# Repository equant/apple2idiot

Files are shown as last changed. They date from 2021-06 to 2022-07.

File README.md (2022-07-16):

# apple2idiot card
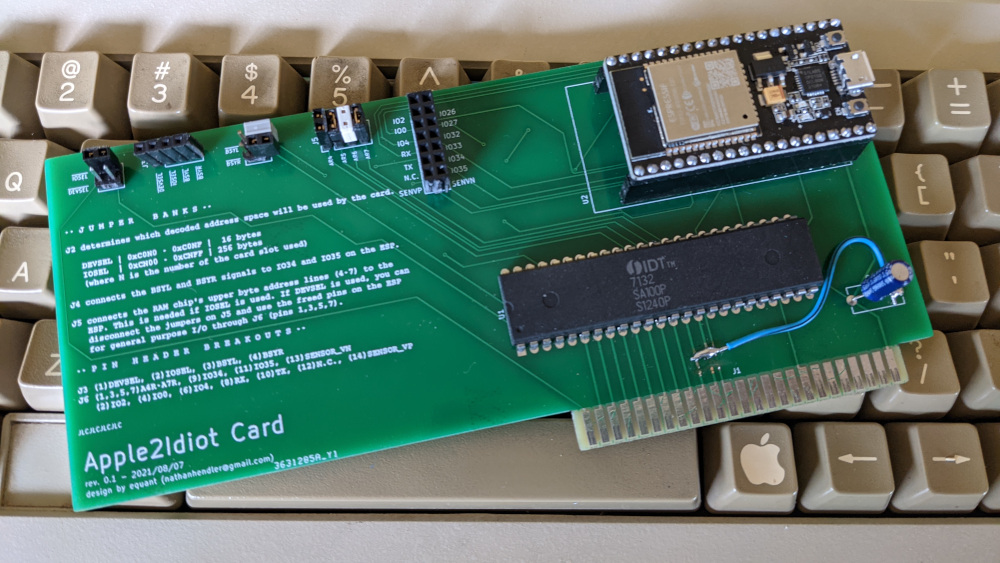
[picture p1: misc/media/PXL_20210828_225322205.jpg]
<br>
A general purpose ESP32 Wifi and Bluetooth board for the Apple II family of
computers (with expansion slots).  

This card is essentially an ESP32 module and a dual-port ram chip.  The Apple
computer and the ESP communicate via the dual-port ram.  That means that the
ESP32 doesn't acutally have access to read/write any of the Apple computer's
data or address busses.  I think that's ok.  In fact, I think this card is so
simple, and stupid, that lots of fun little things can be done with it, but
it's not meant to "get your Apple on the internet".

As a user of the card, you write the software that runs on the ESP32 module,
and the software that runs on the Apple computer.  In the `examples/` folder
are examples of how to do simple little things.  Software on the apple just
peeks/pokes commands and data to the ram chip, and the ESP responds however
it's programmed to resppond.

## Some of the example programs that have been developed so far

* Send a message to Slack.
* Get current weather conditions for a city.
* Select Wifi AP.
* Dedicated rot13 string encoder.

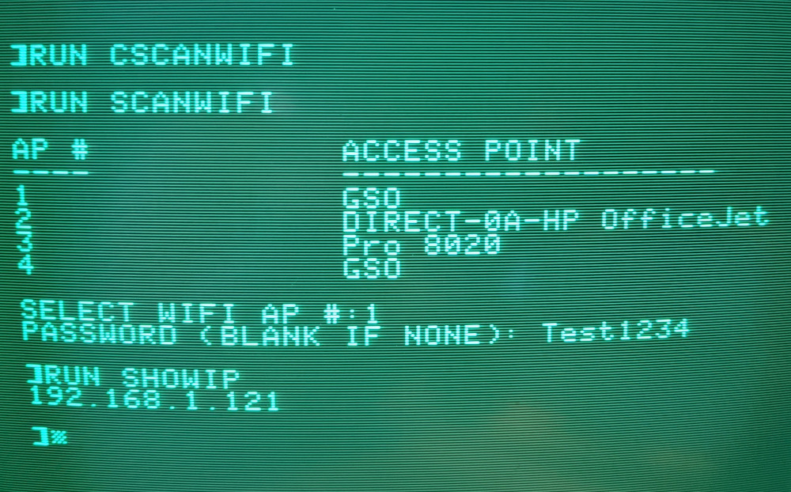
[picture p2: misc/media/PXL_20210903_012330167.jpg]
<br>

## Status

### The Card

This is actively being developed (as of July 2022).  The rev 0.2 boards have arrived, and they work as designed.  The gerber files are here in the repo.

### The Apple II Software

There are examples written in BASIC and in cc65 in the `examples/` directory.

### The Card Software/Firmware

The ESP32 can be programmed using whatever you want.  For example, you can use
the Arduino IDE/C++ or you can use Lua, or Espressif's environment.  Example
Arduino programs are in the repo under examples.

## What could be done with an Apple2Idiot card?

Here are some things I'm interested in making work...

* Prodos clock driver (NTP -> ESP -> Prodos)
* Home automation using MQTT
* Peer-to-peer local area chat/games using ESPNOW or something similar
* Wikipedia access

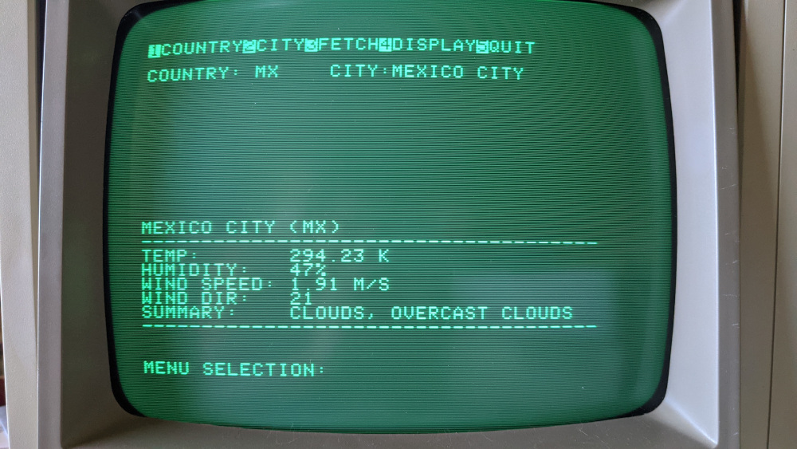
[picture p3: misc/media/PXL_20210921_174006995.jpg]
<br>

## Want to help?

There are lots of jobs both little and big and hard and easy for someone
looking for a project to join.  Take a look at the list above for ideas.  Feel
free to email me at nathanhendler@gmail.com.

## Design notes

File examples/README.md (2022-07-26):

# apple2idiot

## Potential requirements

Some of these examples require things.  Here are some notes I've been taking...

### Arduino Libraries

+ https://github.com/me-no-dev/ESPAsyncWebServer
+ https://github.com/me-no-dev/AsyncTCP
+ ArduinoJSON by Benoit Blanchon

Instructions for installing Arduino libraries: https://www.arduino.cc/en/Guide/Libraries

Download the zips from github...

```bash
cd ~/Arduino/libraries
unzip AsyncTCP-master.zip
unzip ESPAsyncWebServer-master.zip
mv AsyncTCP-master AsyncTCP
mv ESPAsyncWebServer-master ESPAsyncWebServer
```

For ESP32 webserver to serve static files...

+ https://github.com/me-no-dev/arduino-esp32fs-plugin

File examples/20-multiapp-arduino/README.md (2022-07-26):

# Arduno sketch for Apple2 Internet Weather Client Examples

For now, this works with both the basic and and cc65 clients

`../15_fixed_essid_weather-basic`
`../15_fixed_essid_weather-cc65`

if arduino-cli compile --fqbn esp32:esp32:nodemcu-32s .; then arduino-cli upload -p /dev/ttyUSB0 --fqbn esp32:esp32:esp32-poe-iso .; fi

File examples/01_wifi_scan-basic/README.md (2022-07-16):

# Overview

This is a very simple example of how to scan for wifi access points and then
connect to one.  It is a very basic example of how the Apple2Idiot card and the
Apple II can work together.  Practically, this example isn't very useful,
because after you connect you can not really do anything except recscan.
There's no code in `01_wifi_scan-basic.ino` to do anything else.  

## Getting it to work

#. Load `01_wifi_scan-basic.dsk` into your Apple II
#. Load `01_wifi_scan-basic.ino` into your apple2idiot card in slot 2.

At BASIC prompt on Apple II do...

```BASIC
RUN CWIFISCAN.BAS
RUN WIFISCAN.BAS
RUN SHOWIP.BAS
```

CWIFISCAN tells the card to scan for access points.

WIFISCAN shows the results, and lets you choose an access point and enter a password

SHOWIP does just that.

## Building the .dsk image

```bash
. ./make-disk.bash
```

## Flashing card using arduino-cli

You can use the arduino ide to get the .ino file onto the Apple2Idiot card.  Or you can use the `arduino-cli` which is explained here...

```bash
arduino-cli compile --fqbn esp32:esp32:nodemcu-32s .
arduino-cli upload -p /dev/ttyUSB0 --fqbn esp32:esp32:esp32-poe-iso .
```

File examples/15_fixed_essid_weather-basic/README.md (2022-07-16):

# Very simple Apple II Internet weather client example

* Use the arduino-cli or ide to transfer `../15_fixed_essid_weather-arduino/15_fixed_essid_weather-arduino.ino` to the ESP32 on the apple2idiot card.
* Use `WEATHER.BAS` on your Apple ][.

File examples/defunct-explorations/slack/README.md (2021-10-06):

# ESP32 Slack code for apple2idiot

```
~/.arduino15/packages/esp32/hardware/esp32/1.0.6/tools/sdk/sdkconfig
```

Set `CONFIG_SPIRAM_USE_MALLOC=y` to use SPI Ram for heap memory.

## Notes

Sun Sep 26 2021
```
Sketch uses 885078 bytes (67%) of program storage space. Maximum is 1310720 bytes.
Global variables use 40784 bytes (12%) of dynamic memory, leaving 286896 bytes for local variables. Maximum is 327680 bytes.

Sketch uses 884910 bytes (67%) of program storage space. Maximum is 1310720 bytes.
Global variables use 40784 bytes (12%) of dynamic memory, leaving 286896 bytes for local variables. Maximum is 327680 bytes.

Sketch uses 885222 bytes (67%) of program storage space. Maximum is 1310720 bytes.
Global variables use 40784 bytes (12%) of dynamic memory, leaving 286896 bytes for local variables. Maximum is 327680 bytes.

Sketch uses 883538 bytes (67%) of program storage space. Maximum is 1310720 bytes.
Global variables use 40784 bytes (12%) of dynamic memory, leaving 286896 bytes for local variables. Maximum is 327680 bytes.

```

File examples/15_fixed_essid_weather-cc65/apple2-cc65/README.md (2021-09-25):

# Apple2 Internet Weather Client Example

This is the C code to compile the software that runs on an Apple2 and makes use
of the Apple2idiot card to display the weather for a given city.

## How I use this

This is how I compile, make a disk and then stage the disk for transfer to my //c using ADTPro.

```
make
make TARGETS=apple2 dsk
cp weather.dsk ~/bin/ADTPro-2.1.0/disks/
```

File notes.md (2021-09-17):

## Debugging board 08/28/2021

What the ESP thinks is address 0x00 (0xC200) is 0xC2FF,49919 to the Apple.
AND the data from the ESP is 192 and the apple sees 3, so the endian is backwards
for the data and logic levels for the address are flipped.

## Needed changes to board

DONE: Add a GND and +5V breakout.
Fix DEVSEL address in silkscreen docs.
DONE: Unconnect addresses above A7.
DONE: Add diode to +5V.
DONE: Move ESP32 towards keyboard to accomodate USB
Software reset of ESP32

## Potential Trivial Features

+ Gives each computer a unique ID (MAC address)
+ Prodos driver for NPT time.

## Thanks

Renee
flux
c2t

## Ordered:

* 5PCS IDT7132SA100P IDT7132SA DIP-48 HIGH-SPEED 2K x 8 DUAL-PORT STATIC RAM 
* STM32F411 "BlackPill" Development Board

## Misc

* https://pastebin.com/raw/1kR0vbRA

## ESP32 Interupt Issues

* ESP32 Thread I started: https://esp32.com/viewtopic.php?f=12&t=21855
	* " Consider 74ls373 to latch the value to be processed by software."
	* It might also be worth trying ESP32's assembly high-level interrupts. I've never used them personally, but they can allegedly give interrupt latencies that are significantly lower than the ~2us for regular ESP32 C interrupts.
		* See: https://esp32.com/viewtopic.php?t=422
		* See: https://docs.espressif.com/projects/esp ... rupts.html
	* components/esp_system/port/soc/esp32/dport_panic_highint_hdl.S

## Python binar/hex/dec manipulation

```
In [11]: format(10, '016b')
Out[11]: '0000000000001010'

bin(10)
```

## Jumper and Breakout pins

* Input (to ESP32) only
    ~IOSEL  (from Apple2)
    ~BSYL   (from Apple2 side of IDT7132)
    ~BSYR   (from ESP32 side of IDT7132)

+ Apple II Pins to header
    + IOSEL
    + DEVSEL
    + IOSTROBE
+ IDT7132S Pins to header
    + BSYL
    + BSYR
+ ESP32 Pins to header
    + GPIO 0
    + GPIO 1    (TX)
    + GPIO 2
    + GPIO 3    (RX)
    + GPIO 4
    + GPIO 26
    + GPIO 27
    + GPIO 32
    + GPIO 33
    + GPIO 34   (input only) No pullup, needs resistor?
    + GPIO 35   (input only) No pullup, needs resistor?
    + SENSOR_VP (input only) No pullup, needs resistor?
    + SENSOR_VN (input only) No pullup, needs resistor?

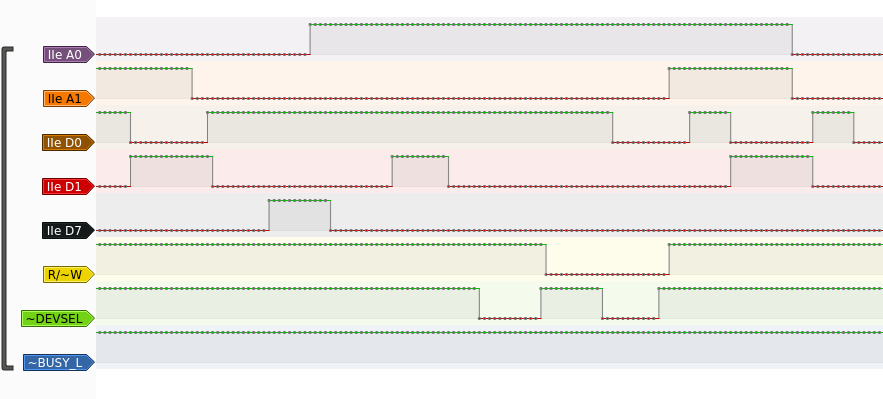
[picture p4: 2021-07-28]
misc/media/pulseview_poke_double_devsel-cropped.png

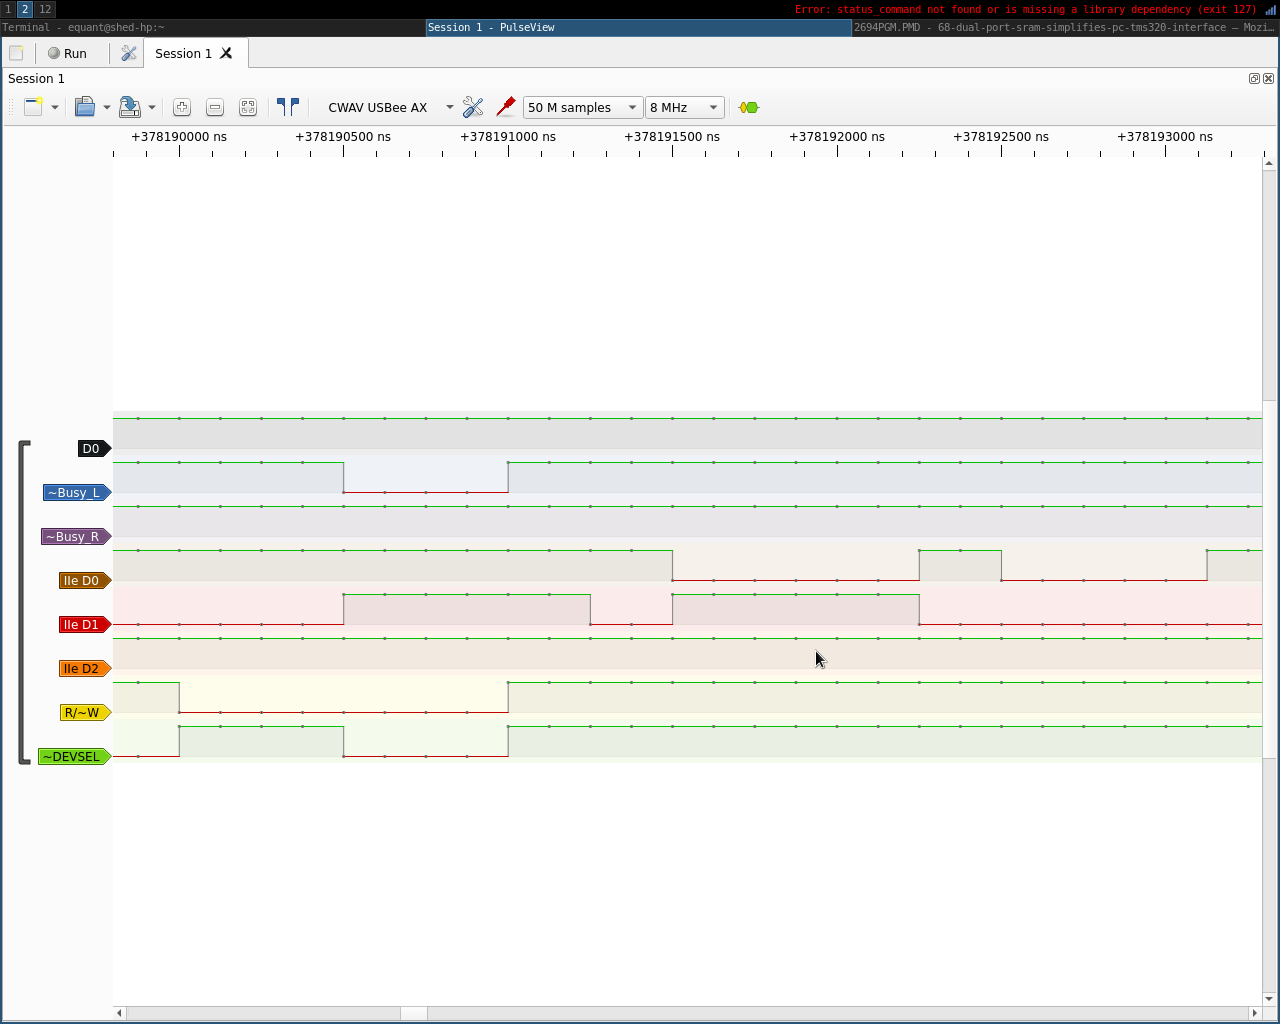
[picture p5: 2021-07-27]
misc/media/pulseview_busy.png

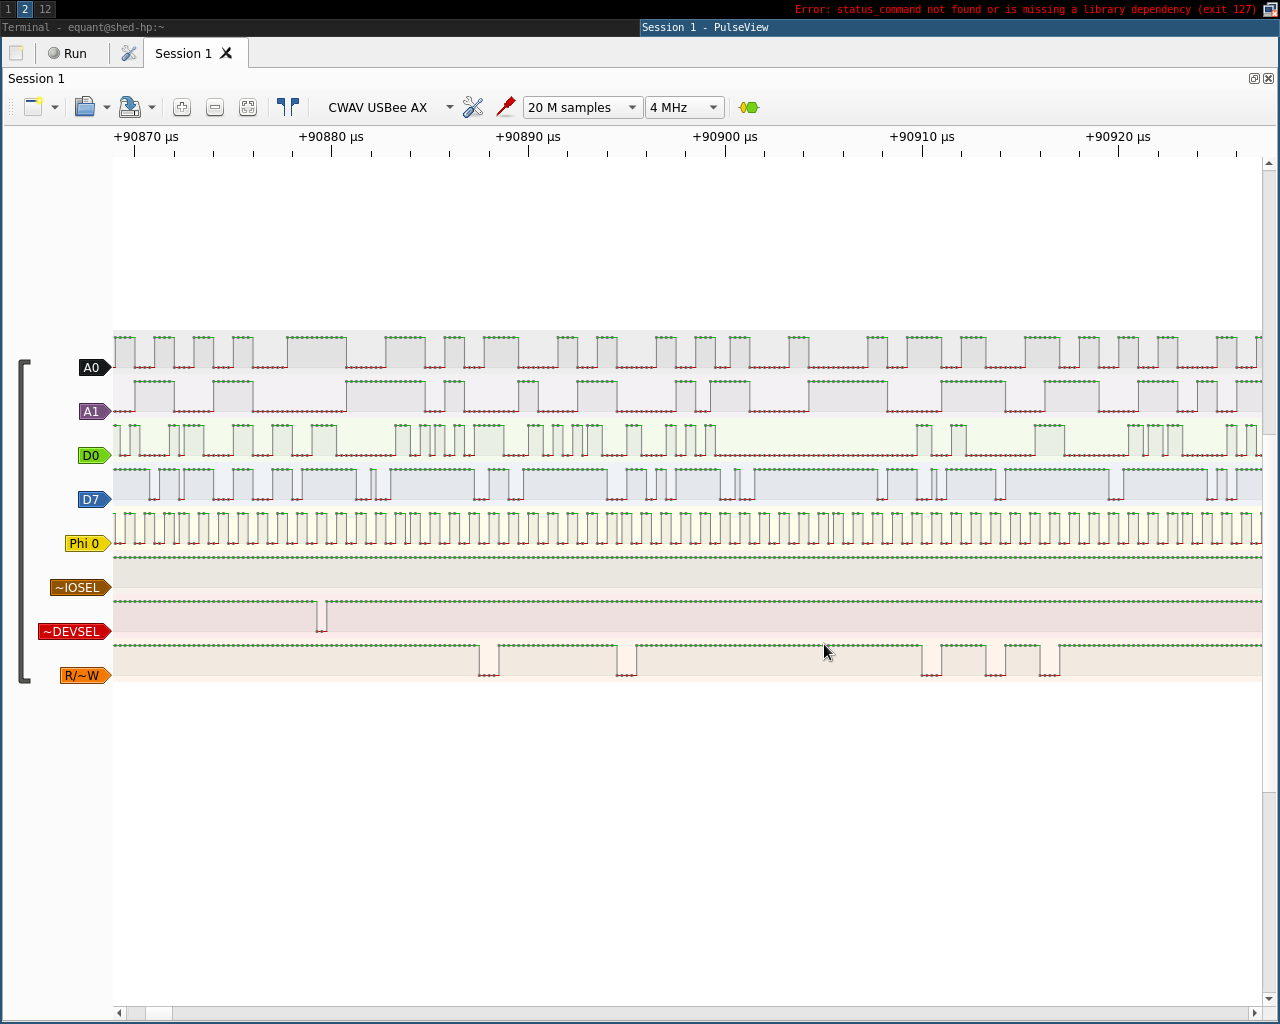
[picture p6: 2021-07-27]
misc/media/pulseview_devsel.png

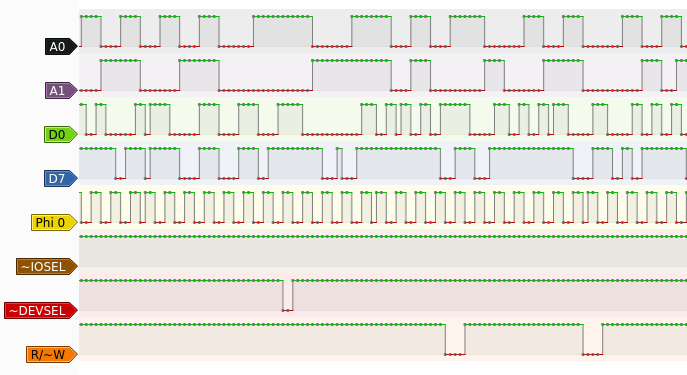
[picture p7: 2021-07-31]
misc/media/pulseview_devsel-cropped.png

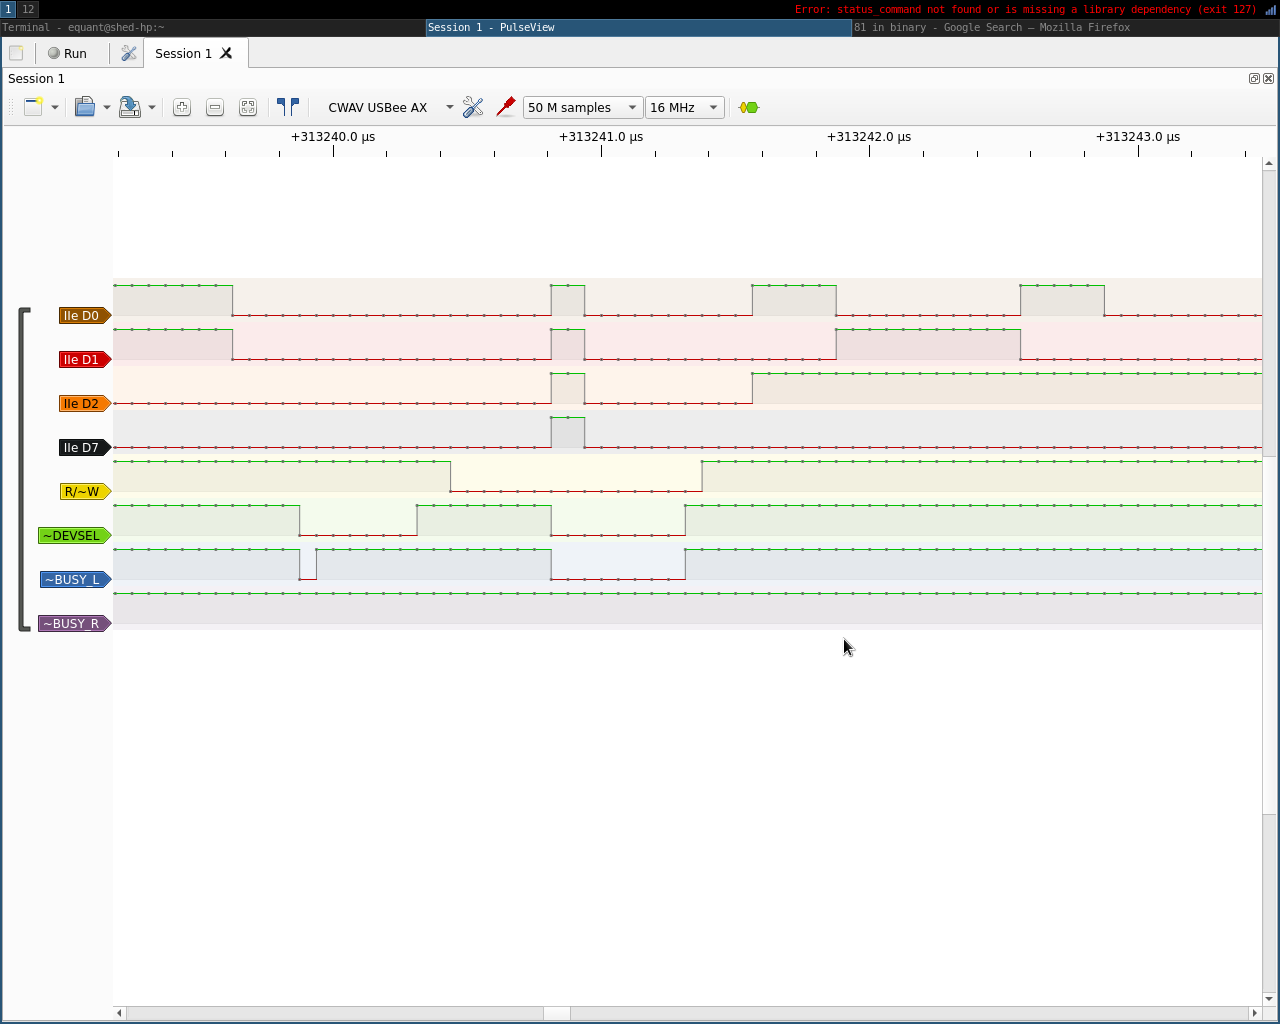
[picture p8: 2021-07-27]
misc/media/pulseview_why_write_no_work.png

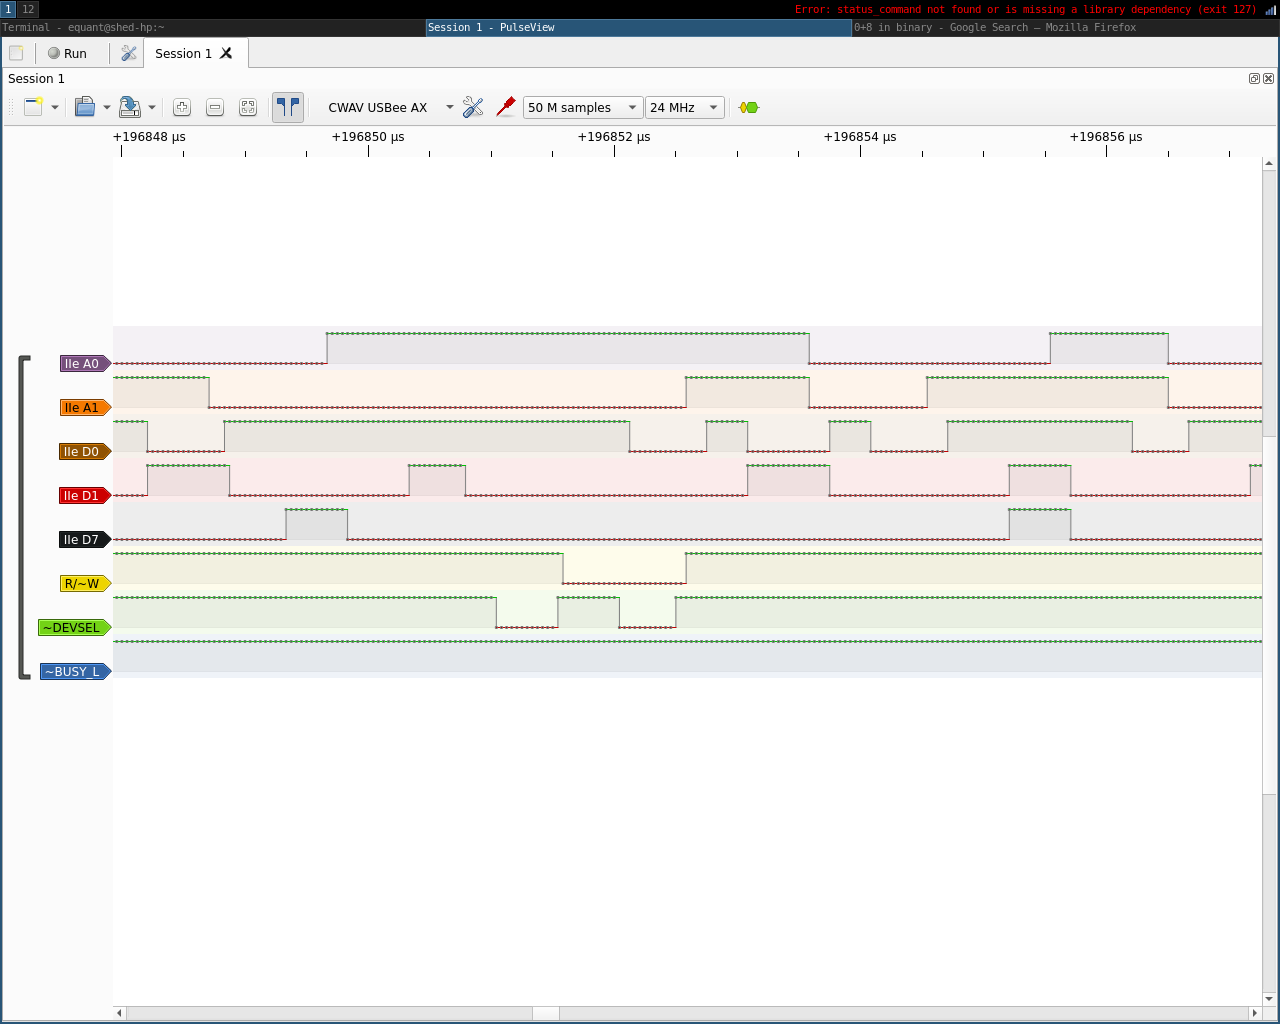
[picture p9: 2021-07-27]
misc/media/pulseview_poke_double_devsel.png

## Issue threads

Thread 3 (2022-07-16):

Second time displaying weather (cc65 implementation) prints garbage

equant, 2022-07-16:
The cc65 version of the Apple 2 weather software works the first time you choose `[4]DISPLAY`.  But, the second time you select it, garbage prints out to the screen.

This problem doesn't exist in the BASIC version, and isn't happening because of the `.ino` code running on the card.

It is likely because I don't know how to program in C, and there's some pointer thing happening I don't understand.

equant, 2022-07-16:
https://github.com/equant/apple2idiot/tree/main/examples/15_fixed_essid_weather-cc65

equant, 2022-07-16:
That was easy.  just needed to add address=0 to beginning of display case.

Closed 2022-07-16.

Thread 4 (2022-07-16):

Handle multiple apps in ESP32.

equant, 2022-07-16:
I started working on a method of handling multiple apps.  This was mostly finished with the chess system.  I need to finish it, and create an example that does weather and chess (or something else).  This issue is for that branch.

Closed 2022-07-26.

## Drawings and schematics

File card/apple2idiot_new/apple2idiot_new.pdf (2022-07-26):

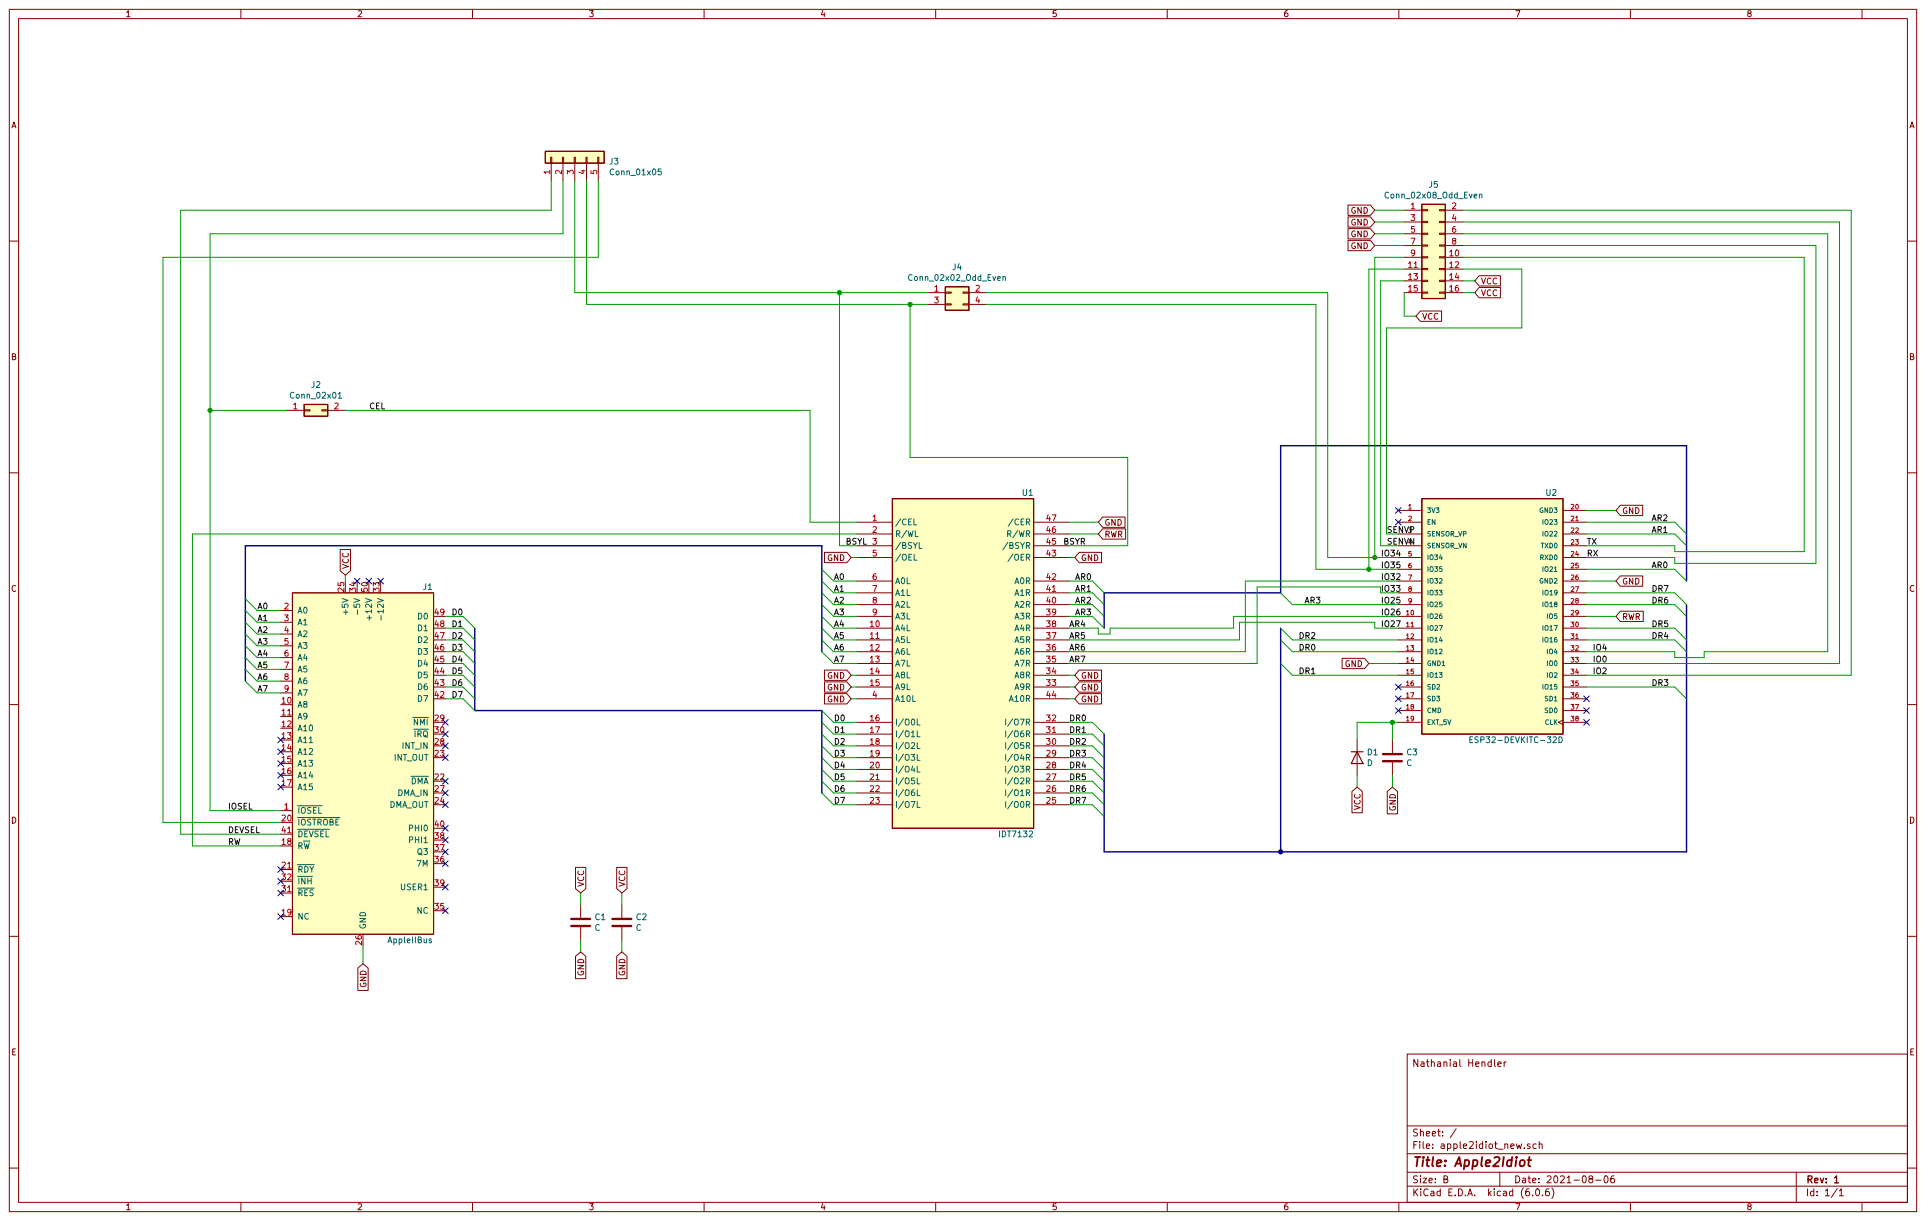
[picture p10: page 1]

11 | 12
13 | 14

File: apple2idiot_new.sch Sheet: / Nathanial Hendler

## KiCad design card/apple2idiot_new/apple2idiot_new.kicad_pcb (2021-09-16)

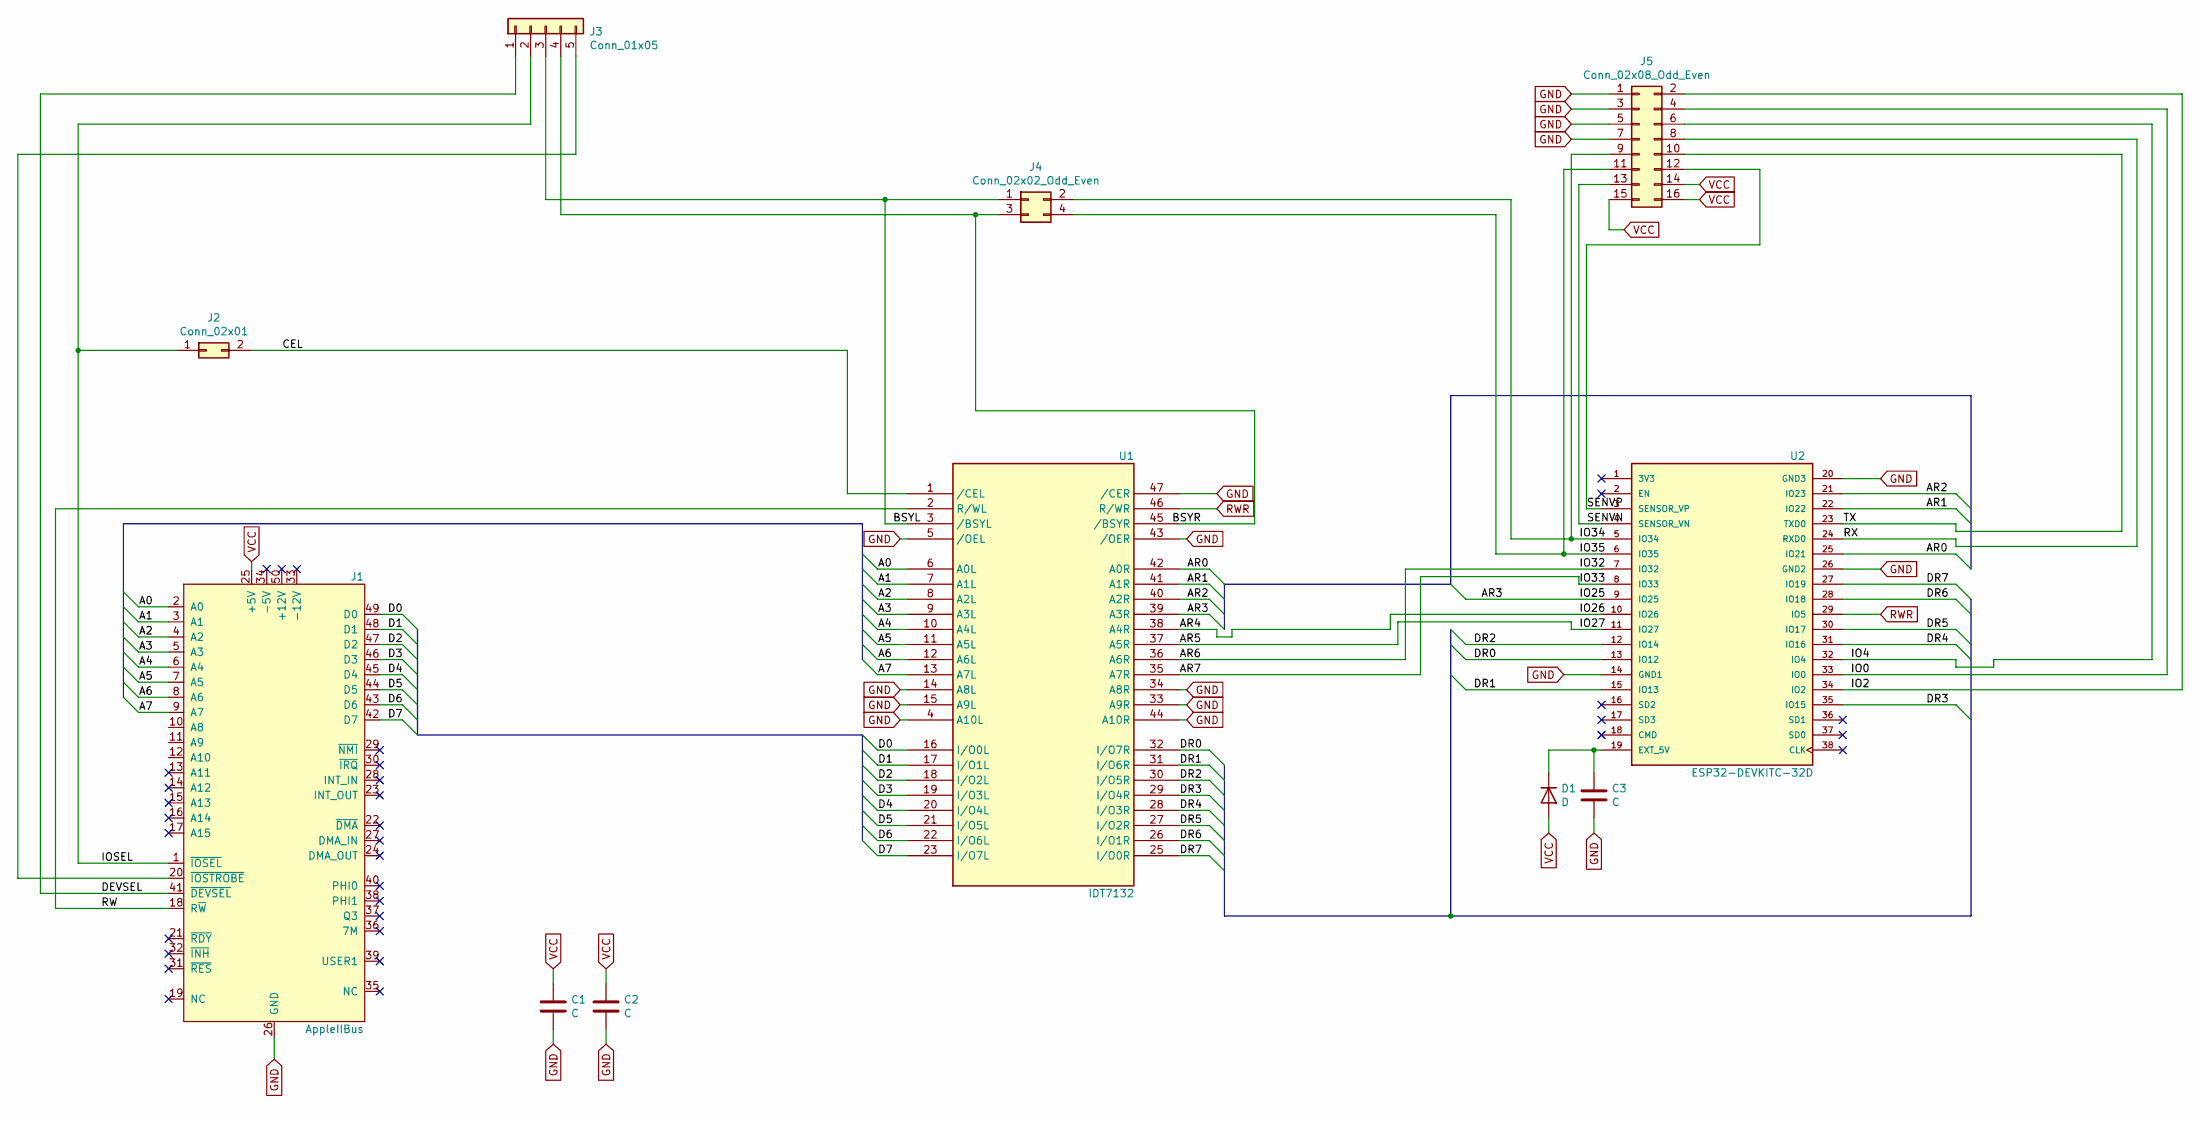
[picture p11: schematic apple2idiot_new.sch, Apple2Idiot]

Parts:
C1, C2, C3: C; C_Rect_L4.6mm_W2.0mm_P2.50mm_MKS02_FKP02
D1: D; D_DO-41_SOD81_P10.16mm_Horizontal
J1: AppleIIBus
J2: Conn_02x01; PinSocket_1x02_P2.54mm_Vertical
J3: Conn_01x05; PinSocket_1x05_P2.54mm_Vertical
J4: Conn_02x02_Odd_Even; PinHeader_2x02_P2.54mm_Vertical
J5: Conn_02x08_Odd_Even; PinSocket_2x08_P2.54mm_Vertical
U1: IDT7132; DIP-48_W15.24mm_LongPads
U2: ESP32-DEVKITC-32D; MODULE_ESP32-DEVKITC-32D; PARTREV 4

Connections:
/A0: J1.2 (A0), U1.6 (A0L)
/A1: J1.3 (A1), U1.7 (A1L)
/A2: J1.4 (A2), U1.8 (A2L)
/A3: J1.5 (A3), U1.9 (A3L)
/A4: J1.6 (A4), U1.10 (A4L)
/A5: J1.7 (A5), U1.11 (A5L)
/A6: J1.8 (A6), U1.12 (A6L)
/A7: J1.9 (A7), U1.13 (A7L)
/AR0: U1.42 (A0R), U2.25 (IO21)
/AR1: U1.41 (A1R), U2.22 (IO22)
/AR2: U1.40 (A2R), U2.21 (IO23)
/AR3: U1.39 (A3R), U2.9 (IO25)
/AR4: U1.38 (A4R), U2.10 (IO26)
/AR5: U1.37 (A5R), U2.11 (IO27)
/AR6: U1.36 (A6R), U2.7 (IO32)
/AR7: U1.35 (A7R), U2.8 (IO33)
/BSYL: J3.3, J4.1, U1.3 (/BSYL)
/CEL: J2.2, U1.1 (/CEL)
/D0: J1.49 (D0), U1.16 (I/O0L)
/D1: J1.48 (D1), U1.17 (I/O1L)
/D2: J1.47 (D2), U1.18 (I/O2L)
/D3: J1.46 (D3), U1.19 (I/O3L)
/D4: J1.45 (D4), U1.20 (I/O4L)
/D5: J1.44 (D5), U1.21 (I/O5L)
/D6: J1.43 (D6), U1.22 (I/O6L)
/D7: J1.42 (D7), U1.23 (I/O7L)
/DEVSEL: J1.41 (~DEVSEL), J3.1
/DR0: U1.32 (I/O7R), U2.13 (IO12)
/DR1: U1.31 (I/O6R), U2.15 (IO13)
/DR2: U1.30 (I/O5R), U2.12 (IO14)
/DR3: U1.29 (I/O4R), U2.35 (IO15)
/DR4: U1.28 (I/O3R), U2.31 (IO16)
/DR5: U1.27 (I/O2R), U2.30 (IO17)
/DR6: U1.26 (I/O1R), U2.28 (IO18)
/DR7: U1.25 (I/O0R), U2.27 (IO19)
/IO0: J5.4, U2.33 (IO0)
/IO2: J5.2, U2.34 (IO2)
/IO4: J5.6, U2.32 (IO4)
/IO34: J4.2, J5.9, U2.5 (IO34)
/IO35: J4.4, J5.11, U2.6 (IO35)
/IOSEL: J1.1 (~IOSEL), J2.1, J3.2
/RW: J1.18 (R~W), U1.2 (R/WL)
/RX: J5.8, U2.24 (RXD0)
/SENVN: J5.13, U2.4 (SENSOR_VN)
/SENVP: J5.12, U2.3 (SENSOR_VP)
/TX: J5.10, U2.23 (TXD0)
GND: C1.2, C2.2, C3.2, J1.26 (GND), J5.1, J5.3, J5.5, J5.7, U1.4 (A10L), U1.5 (/OEL), U1.14 (A8L), U1.15 (A9L), U1.24 (GND), U1.33 (A9R), U1.34 (A8R), U1.43 (/OER), U1.44 (A10R), U1.47 (/CER), U2.14 (GND1), U2.20 (GND3), U2.26 (GND2)
unnamed: C3.1, D1.1 (K), U2.19 (EXT_5V)
unnamed: J1.20 (~IOSTROBE), J3.5
unnamed: J3.4, J4.3, U1.45 (/BSYR)
RWR: U1.46 (R/WR), U2.29 (IO5)
VCC: C1.1, C2.1, D1.2 (A), J1.25 (+5V), J5.14, J5.15, J5.16, U1.48 (VCC)

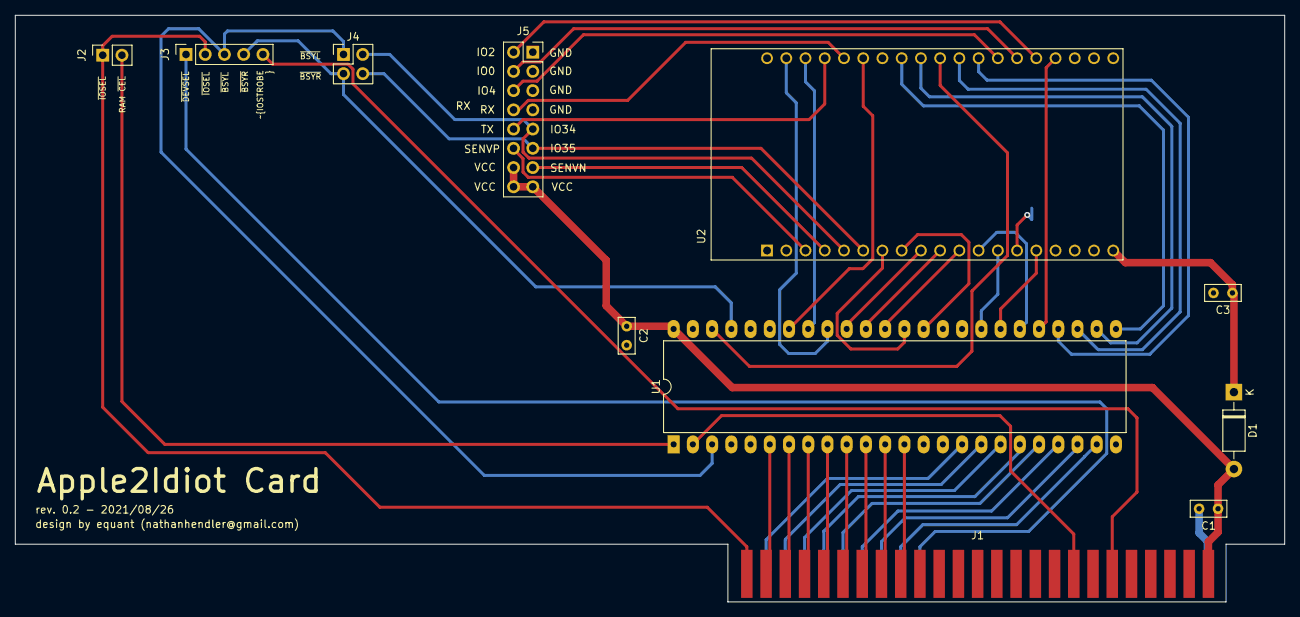
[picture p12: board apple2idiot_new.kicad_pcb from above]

Board: 2 copper layers, 167.6 x 77.5 mm, 11 parts (0 on the bottom side), 52 nets.

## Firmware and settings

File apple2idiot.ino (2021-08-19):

/*
blah blah blah
*/

#define DEBUG true

// Load Wi-Fi library
#include <WiFi.h>
#include <ESPAsyncWebServer.h>
#include <SPIFFS.h>
#include <HTTPClient.h>
#include <ArduinoJson.h>

/**************/
/* ESP32 Pins */
/**************/

/* DATA BUS (numbers mean GPIO port) */
#define D0R 12
#define D1R 13
#define D2R 14
#define D3R 15
#define D4R 18
#define D5R 19
#define D6R 21
#define D7R 22
byte data_pins[] = {D0R, D1R, D2R, D3R, D4R, D5R, D6R, D7R};
#define DATA_BUS_SIZE 8

/* Address Bus */
#define A0R 23
#define A1R 25
#define A2R 26
#define A3R 27
byte address_pins[] = {A0R, A1R, A2R, A3R};
#define ADDRESS_BUS_SIZE 4

/* IDT7132S dual port ram chip enable */
#define RW_PIN      5
#define RW_WRITE    LOW
#define RW_READ     HIGH

unsigned int data_byte = 0;
                                            //    fisrt bit is a flag for if the data is from Apple or from ESP32.
                                            //   /     
                                            //  /       last bit is a flag for "more data waiting to be sent".
                                            // /       /
#define COMMAND_FROM_APPLE          0       // 0_______
#define COMMAND_FROM_ESP          128       // 1_______
#define COMMAND_MORE_DATA_WAITING   1       // _0000001
#define COMMAND_NO_DATA_WAITING     0       // _0000001

#define COMMAND_GENERIC_MESSAGE     2       // _000001_
#define COMMAND_FETCH_WEATHER       4       // _000010_
#define COMMAND_SEND_LONG_STRING   12       // _000110_
#define COMMAND_FORMAT_RAM        126       // _111111_

#define ETX 3   // ASCII "End of Text" (ETX) character

/************/
/* Interupt */
/************/

/* Variables shared between ISR and main code need to be volatile */
volatile bool isr_handled = false;
volatile uint32_t raw_register_read;
volatile uint16_t raw_register1_read;

/**********************/
/* WiFi and Webserver */
/**********************/

// Replace with your network credentials
const char* wifi_ssid = "GSO";
const char* wifi_password = "xerxes27";
AsyncWebServer web_server(80);
//WebServer web_server(80);

/*******************/
/* Weather Service */
/*******************/

const String weather_service_api_key= "0ab97bbbea58592d7c9d64067a34d2d0";
const String weather_url = "http://api.openweathermap.org/data/2.5/weather?";

/*********/
/* Misc. */
/*********/

const long readLoopInterval = 10000; // millis
unsigned long lastReadLoopTime = 0;
//byte ram[ADDRESS_BUS_SIZE];
byte ram[16];
volatile byte ram_busy=0;
//const unsigned int RAM_BUSY=666;
#define RAM_BUSY 666

/*################################################
#                      ISR                       #
################################################*/

void IRAM_ATTR isrDEVSEL(void) {
    raw_register_read = REG_READ(GPIO_IN_REG);
    raw_register1_read = REG_READ(GPIO_IN1_REG);
    isr_handled = true;
}

/*################################################
#                   Functions                    #
################################################*/

boolean set_address(int address) {
    if (ram_busy) {
        Serial.println("BUSY");        
        return false;
    }
    ram_busy = true;
    //Serial.print("    Setting address (");
    //Serial.print(address);
    //Serial.println(")");
    //delay(20);
    Serial.print("    A:");        
    for (byte i=0; i<ADDRESS_BUS_SIZE; i++) {
        byte state = bitRead(address, i);
        digitalWrite(address_pins[i], state);
        Serial.print(state);
    }
    Serial.println();
    return true;
}

unsigned int read_data(int address) {
    Serial.print("READ: ");
    Serial.println(address);        
    byte data_bus_read = 0;
    if (set_address(address)) {
        digitalWrite(RW_PIN, RW_READ);  // Should already be set to RW_READ, but just in case.
        Serial.print("    D:");        
        for (byte i=0; i<DATA_BUS_SIZE; i++) {
            byte pin_state = digitalRead(data_pins[i]);
            data_bus_read += pin_state * pow(2,i);
            Serial.print(pin_state);        
        }
        Serial.println();
        ram_busy = false;
        return data_bus_read; 
    } else {
        return RAM_BUSY;
    }
}

//signed int convert_to_signed_byte(byte byte_to_convert) {
    //if (abs(requested_byte_to_write) > 127) {
    //if (requested_byte_to_write < 0) {

boolean write_data(byte address, byte byte_to_write) {
    Serial.print("WRITE: ");
    Serial.print(byte_to_write);        
    Serial.print(" -> ");
    Serial.println(address);        
    if (set_address(address)) {
        //set_address(address);
        Serial.print("    D:");        
        for (byte i=0; i<DATA_BUS_SIZE; i++) {
            byte bit_to_write = (byte_to_write >> i) & 0b00000001;
            pinMode(data_pins[i], OUTPUT);
            digitalWrite(data_pins[i], bit_to_write);
            Serial.print(bit_to_write);        
        }
        Serial.println();        
        digitalWrite(RW_PIN, RW_WRITE);
        delay(1);
        digitalWrite(RW_PIN, RW_READ);
        for (byte i=0; i<DATA_BUS_SIZE; i++) {
            pinMode(data_pins[i], INPUT);
        }
        ram_busy = false;
        return true;
    } else {
        return false;
    }
}


void store_ip_to_ram(byte offset) {
    IPAddress ip_address = WiFi.localIP();
    for (int i=0; i < ADDRESS_BUS_SIZE; i++) {
        write_data(i+offset, ip_address[i]);
    }
}

void send_string_to_apple(String string_to_send, byte command_message) {
    if (string_to_send.length() > 15 - 1) { // - 1 because of null character at end of string.
    } else {
        int c=0;
        for (c=0; c < string_to_send.length(); c++) {
            write_data(c, string_to_send[c]);
        }
        write_data(c+1, ETX);
        write_data(15, COMMAND_FROM_ESP + command_message + COMMAND_NO_DATA_WAITING);
    }
}

void fetch_weather(char* city_name) {
    HTTPClient http;
    //http.begin(String(weather_url) + "?q=Tucson,us&APPID=" + String(weather_service_api_key));
    const String request_url = weather_url + "q=Tucson,us&APPID=" + weather_service_api_key;
    Serial.println(request_url);
    http.begin(request_url);
    int httpCode = http.GET();  //Make the request
    delay(10);
 
    if (httpCode > 0) { //Check for the returning code
        String payload = http.getString();
        //Serial.println(httpCode);
        Serial.println("++++++++++++++++++++++++");
        Serial.println(payload);
        Serial.println("++++++++++++++++++++++++");
        StaticJsonDocument<200> filter;
        filter["weather"][0]["main"]        = true;
        filter["weather"][0]["description"] = true;
        filter["main"]["humidity"]          = true;
        filter["main"]["temp"]              = true;
        filter["wind"]["speed"]             = true;
        filter["wind"]["deg"]               = true;
        StaticJsonDocument<400> doc;
        DeserializationError error = deserializeJson(doc, payload, DeserializationOption::Filter(filter));
        //DeserializationError error = deserializeJson(doc, payload);
        if (error) {
            Serial.print(F("deserializeJson() failed: "));
            Serial.println(error.f_str());
        } else {
            //const char* main = doc["main"];
            Serial.println("----------------------");
            serializeJsonPretty(doc, Serial);
            Serial.println("----------------------");
            serializeJsonPretty(doc["wind"], Serial);
            Serial.println("----------------------");
            int temp       = doc["main"]["humidity"];
            int humidity   = doc["main"]["humidity"];
            float wind_speed = doc["wind"]["speed"];
            int wind_deg   = doc["wind"]["speed"];
            String weather_description = doc["weather"][0]["description"];
            write_data(0, round(temp-273.15));
            write_data(1, round(humidity));
            write_data(2, round(wind_deg/10));      // divide by twn because 360 is too big for 8 bits
            write_data(3, round(wind_speed));
                
        }

    }
 
    else {
      Serial.println("Error on HTTP request");
    }
 
    http.end(); //Free the resources
}

void read_ram() {
    for (int i=0; i < 16; i++) {
        unsigned int foo = read_data(i);
        ram[i] = foo;
    }
}

String html_template_processor(const String& var) {
    Serial.println("html_template_processor()");
    String return_string = "";
    if (var == "RAM_TABLE") {
        read_ram();
        for (int i=0; i < 16; i++) {
            return_string += "<tr><td>"+String(i)+"</td><td>" + String(ram[i]) + "</td></tr>\n";
        }
        return return_string;
    }
    return var;
}
        

void www_weather(AsyncWebServerRequest *request) {
    fetch_weather("Tucson");
    request->send(SPIFFS, "/ram.htm", String(), false, html_template_processor);
}
void www_root(AsyncWebServerRequest *request) {
    request->send(SPIFFS, "/index.htm", String(), false, html_template_processor);
}
void www_ram(AsyncWebServerRequest *request) {
    request->send(SPIFFS, "/ram.htm", String(), false, html_template_processor);
}
void www_write_byte(AsyncWebServerRequest *request) {
    Serial.println("www_write_byte()");
    String address;
    String data_byte;
    if (request->hasParam("address")) {
        address = request->getParam("address")->value();
        //Serial.println("Found address: "+address);
        if (request->hasParam("data")) {
            data_byte = request->getParam("data")->value();
            //Serial.println("Found data: "+data_byte);
            write_data(address.toInt(), data_byte.toInt());
        }
    }
    request->send(SPIFFS, "/ram.htm", String(), false, html_template_processor);
}
void www_css(AsyncWebServerRequest *request) {
    request->send(SPIFFS, "/a2i.css", "text/css");
}

void prefill_ram_with_pattern_data() {
    write_data(15, 0);      // notify Apple IIe we are done processing command byte
    write_data(14, 123);      // notify Apple IIe we are done processing command byte
    write_data(13, 1);      // notify Apple IIe we are done processing command byte
    write_data(12, 123);      // notify Apple IIe we are done processing command byte
    write_data(11, 2);      // notify Apple IIe we are done processing command byte
    write_data(10, 123);      // notify Apple IIe we are done processing command byte
    write_data(9, 3);      // notify Apple IIe we are done processing command byte
    write_data(8, 123);      // notify Apple IIe we are done processing command byte
    write_data(7, 4);      // notify Apple IIe we are done processing command byte
    write_data(6, 123);      // notify Apple IIe we are done processing command byte
    write_data(5, 5);      // notify Apple IIe we are done processing command byte
    write_data(4, 123);      // notify Apple IIe we are done processing command byte
    write_data(3, 6);      // notify Apple IIe we are done processing command byte
    write_data(2, 123);      // notify Apple IIe we are done processing command byte
    write_data(1, 7);      // notify Apple IIe we are done processing command byte
    write_data(0, 123);      // notify Apple IIe we are done processing command byte
}

/*################################################
#                     Setup                      #
################################################*/

void setup() {

    /* Configure ESP32 Pins */
    pinMode(A0R, OUTPUT); digitalWrite(A0R, LOW);
    pinMode(A1R, OUTPUT); digitalWrite(A1R, LOW);
    pinMode(A2R, OUTPUT); digitalWrite(A2R, LOW);
    pinMode(A3R, OUTPUT); digitalWrite(A3R, LOW);
    pinMode(D0R, INPUT);
    pinMode(D1R, INPUT);
    pinMode(D2R, INPUT);
    pinMode(D3R, INPUT);
    pinMode(D4R, INPUT);
    pinMode(D5R, INPUT);
    pinMode(D6R, INPUT);
    pinMode(D7R, INPUT);
    pinMode(RW_PIN, OUTPUT); digitalWrite(RW_PIN, RW_READ);

    delay(10);
    //wifi_scan();

    /* Connect to wifi */
    Serial.begin(115200);
    Serial.println("");
    Serial.println("Starting wifi...");
    Serial.print("  connecting to: ");
    Serial.println(wifi_ssid);

    WiFi.begin(wifi_ssid, wifi_password);
    while (WiFi.status() != WL_CONNECTED) {
        delay(900);
        Serial.print(".");
    }
    Serial.println("");
    Serial.println("WiFi connected successfully");
    Serial.print("Got IP: ");
    Serial.println(WiFi.localIP());  //Show ESP32 IP on serial
    prefill_ram_with_pattern_data();
    store_ip_to_ram(0);
    //store_ip_to_ram(4);

    /* Start webserver */
    if(!SPIFFS.begin()){
        Serial.println("An Error has occurred while mounting SPIFFS");
    }
    web_server.on("/", HTTP_GET, www_root);
    web_server.on("/a2i.css", HTTP_GET, www_css);
    web_server.on("/ram", HTTP_GET, www_ram);
    web_server.on("/write_byte", HTTP_GET, www_write_byte);
    web_server.on("/weather", HTTP_GET, www_weather);
    web_server.on("/heap", HTTP_GET, [](AsyncWebServerRequest *request){
        request->send(200, "text/plain", "Free Heap: " + String(ESP.getFreeHeap()) + " bytes.");
    });

    //web_server.on("/hello", HTTP_GET, [](AsyncWebServerRequest *request){
        //request->send(200, "text/plain", "Hello World");
    //});

    //web_server.on("/", www_root);
    web_server.begin();
    Serial.println("HTTP server started");
    delay(10); 

    /* Display file system contents */
    Serial.println("-----------------------------------------");
    File root_filesystem = SPIFFS.open("/");
    File f = root_filesystem.openNextFile();
    while(f){
        Serial.print("FILE: ");
        Serial.println(f.name());
        f = root_filesystem.openNextFile();
    }
    Serial.println("-----------------------------------------");

    //attachInterrupt(DEVSEL_PIN, isrDEVSEL, LOW);
}

/*################################################
#                      Main                      #
################################################*/

void loop() {
    //if (isr_handled) {
        //data_byte = raw_register_read >> 12 & 0b00000000000011111111;
        //isr_handled = false;
    //}

    if ((millis() - lastReadLoopTime) > readLoopInterval) {
        //Serial.println("+++");
        unsigned int command_byte = read_data(15);
        if (command_byte == RAM_BUSY) {
            Serial.println("Command Read: RAM BUSY");
        }
        else if (command_byte < COMMAND_FROM_ESP) {
            // command came from apple (or webform).
            Serial.print("Command Read: ");
            Serial.println(command_byte);
            //write_data(15, 1);      // notify Apple IIe we are processing command byte
            switch(command_byte) {
                case COMMAND_FETCH_WEATHER:
                    Serial.println("Fetch Weather");
                    fetch_weather("Tucson");
                    break;
                case COMMAND_SEND_LONG_STRING:
                    //send_string_to_apple("This is a long string", COMMAND_GENERIC_MESSAGE); 
                    send_string_to_apple("ABCDE", COMMAND_GENERIC_MESSAGE); 
                case COMMAND_FORMAT_RAM:
                    Serial.println("Calling prefill_ram_with_pattern_data()");
                    prefill_ram_with_pattern_data();
                    write_data(15, 0);      // notify Apple IIe we are done processing command byte
                    break;
            }
            /*
            byte c = 0;
            while (ram_busy && (c < 10)) {
                delay(10);
                c = c+1;
                Serial.print("_");
            }
            Serial.println("^^^^");
            write_data(15, 0);      // notify Apple IIe we are done processing command byte
            read_data(15);      // notify Apple IIe we are done processing command byte
            */
        }
        lastReadLoopTime = millis();
    }
}

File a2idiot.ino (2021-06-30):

/*********
  Rui Santos
  Complete project details at http://randomnerdtutorials.com  
*********/

// Load Wi-Fi library
#include <WiFi.h>
// Replace with your network credentials
const char* ssid = "GSO";
const char* password = "xerxes27";
// Set web server port number to 80
WiFiServer server(80);
// Variable to store the HTTP request
String http_header;

/* OUTPUTS (numbers mean GPIO port) */
#define DATA_0_PIN      9
#define DATA_1_PIN      10
#define DATA_2_PIN      5
#define DATA_3_PIN      5
#define DATA_4_PIN      5
#define DATA_5_PIN      5
#define DATA_6_PIN      5
#define DATA_7_PIN      5

#define DEVSEL_PIN      5

// Auxiliar variables to store the current output state
String output26State = "off";
String output27State = "off";

// Assign output variables to GPIO pins
const int output26 = 26;
const int output27 = 27;

// Current time
unsigned long currentTime = millis();
// Previous time
unsigned long previousTime = 0; 
// Define timeout time in milliseconds (example: 2000ms = 2s)
const long timeoutTime = 2000;

void setup() {
    Serial.begin(115200);
    //Serial.begin(9600);
    // Initialize the output variables as outputs
    //pinMode(output26, OUTPUT);
    //pinMode(output27, OUTPUT);
    // Set outputs to LOW
    //digitalWrite(output26, LOW);
    //digitalWrite(output27, LOW);
    pinMode(DATA_0_PIN, INPUT);
    pinMode(DATA_1_PIN, INPUT);
    pinMode(DATA_2_PIN, INPUT);
    pinMode(DATA_3_PIN, INPUT);
    pinMode(DATA_4_PIN, INPUT);
    pinMode(DATA_5_PIN, INPUT);
    pinMode(DATA_6_PIN, INPUT);
    pinMode(DATA_7_PIN, INPUT);
    pinMode(DEVSEL_PIN, INPUT);

    // Connect to Wi-Fi network with SSID and password
    Serial.print("Connecting to ");
    Serial.println(ssid);
    WiFi.begin(ssid, password);
    while (WiFi.status() != WL_CONNECTED) {
        delay(500);
        Serial.print(".");
    }
    // Print local IP address and start web server
    Serial.println("");
    Serial.println("WiFi connected.");
    Serial.println("IP address: ");
    Serial.println(WiFi.localIP());
    server.begin();
}

void http_check() {
  WiFiClient client = server.available();   // Listen for incoming clients
  if (client) {                             // If a new client connects,
    currentTime = millis();
    previousTime = currentTime;
    //Serial.println("New Client.");          // print a message out in the serial port
    String currentLine = "";                // make a String to hold incoming data from the client
    while (client.connected() && currentTime - previousTime <= timeoutTime) {  // loop while the client's connected
      currentTime = millis();
      if (client.available()) {             // if there's bytes to read from the client,
        char c = client.read();             // read a byte, then
        //Serial.write(c);                    // print it out the serial monitor
        http_header += c;
        if (c == '\n') {                    // if the byte is a newline character
          // if the current line is blank, you got two newline characters in a row.
          // that's the end of the client HTTP request, so send a response:
          if (currentLine.length() == 0) {
            // HTTP headers always start with a response code (e.g. HTTP/1.1 200 OK)
            // and a content-type so the client knows what's coming, then a blank line:
            client.println("HTTP/1.1 200 OK");
            client.println("Content-type:text/html");
            client.println("Connection: close");
            client.println();
            
            // turns the GPIOs on and off
            if (http_header.indexOf("GET /26/on") >= 0) {
              //Serial.println("GPIO 26 on");
              output26State = "on";
              digitalWrite(output26, HIGH);
            } else if (http_header.indexOf("GET /26/off") >= 0) {
              //Serial.println("GPIO 26 off");
              output26State = "off";
              digitalWrite(output26, LOW);
            } else if (http_header.indexOf("GET /27/on") >= 0) {
              //Serial.println("GPIO 27 on");
              output27State = "on";
              digitalWrite(output27, HIGH);
            } else if (http_header.indexOf("GET /27/off") >= 0) {
              //Serial.println("GPIO 27 off");
              output27State = "off";
              digitalWrite(output27, LOW);
            }
            
            // Display the HTML web page
            client.println("<!DOCTYPE html><html>");
            client.println("<head><meta name=\"viewport\" content=\"width=device-width, initial-scale=1\">");
            client.println("<link rel=\"icon\" href=\"data:,\">");
            // CSS to style the on/off buttons 
            // Feel free to change the background-color and font-size attributes to fit your preferences
            client.println("<style>html { font-family: Helvetica; display: inline-block; margin: 0px auto; text-align: center;}");
            client.println(".button { background-color: #4CAF50; border: none; color: white; padding: 16px 40px;");
            client.println("text-decoration: none; font-size: 30px; margin: 2px; cursor: pointer;}");
            client.println(".button2 {background-color: #555555;}</style></head>");
            
            // Web Page Heading
            client.println("<body><h1>ESP32 Web Server</h1>");
            
            // Display current state, and ON/OFF buttons for GPIO 26  
            client.println("<p>GPIO 26 - State " + output26State + "</p>");
            // If the output26State is off, it displays the ON button       
            if (output26State=="off") {
              client.println("<p><a href=\"/26/on\"><button class=\"button\">ON</button></a></p>");
            } else {
              client.println("<p><a href=\"/26/off\"><button class=\"button button2\">OFF</button></a></p>");
            } 
               
            // Display current state, and ON/OFF buttons for GPIO 27  
            client.println("<p>GPIO 27 - State " + output27State + "</p>");
            // If the output27State is off, it displays the ON button       
            if (output27State=="off") {
              client.println("<p><a href=\"/27/on\"><button class=\"button\">ON</button></a></p>");
            } else {
              client.println("<p><a href=\"/27/off\"><button class=\"button button2\">OFF</button></a></p>");
            }
            client.println("</body></html>");
            
            // The HTTP response ends with another blank line
            client.println();
            // Break out of the while loop
            break;
          } else { // if you got a newline, then clear currentLine
            currentLine = "";
          }
        } else if (c != '\r') {  // if you got anything else but a carriage return character,
          currentLine += c;      // add it to the end of the currentLine
        }
      }
    }
    // Clear the header variable
    http_header = "";
    // Close the connection
    client.stop();
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

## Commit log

2021-07-28 triploid catchup
    [apple2idiot.kicad_pcb, apple2idiot.sch]
2021-07-28 ESP32 Reading data from Apple II writes
2021-07-31 ESP w/ webserver writes to RAM
    [apple2idiot.kicad_pcb, apple2idiot.sch]
2021-08-19 going to silver city
    [apple2idiot.kicad_pcb, apple2idiot.sch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]
2021-08-31 Cleaned up rot13 example, and misc catchup from laptop
    [apple2idiot_new.sch]
2021-09-04 Low level ESP ram functions into Apple2Idiot arduino library
2021-09-07 Card work: Diode, no more DEVSEL support, A8-10 grounded, and more
    [apple2idiot_new.kicad_pcb, apple2idiot_new.sch]
2021-09-16 Rev 0.2 card changes, and staging a cc65 weather repo
    [apple2idiot_new-B_Cu.gbr, apple2idiot_new-B_Mask.gbr, apple2idiot_new-B_Paste.gbr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]
2021-09-29 Regression of ESP32 slack code due to memory corruption. Try again later. On to chess!
2022-07-16 Fixed garbage display weather bug #3
    [main.c]
2022-07-18 Context/App ISS/Weather switching example

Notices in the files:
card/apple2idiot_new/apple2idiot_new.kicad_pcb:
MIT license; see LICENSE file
